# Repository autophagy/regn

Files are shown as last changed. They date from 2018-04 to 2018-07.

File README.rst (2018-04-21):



Regn is a weather station. It reads in temperature humidity,
atmospheric pressure and luminosity.

Hardware
========

- `ESP8266 Huzzah`_
- `DHT22 temperature & humidity sensor`_
- `BMP180 barometric pressure sensor`_
- `TSL2561 luminosity/lux/light sensor`_

Schematic
---------

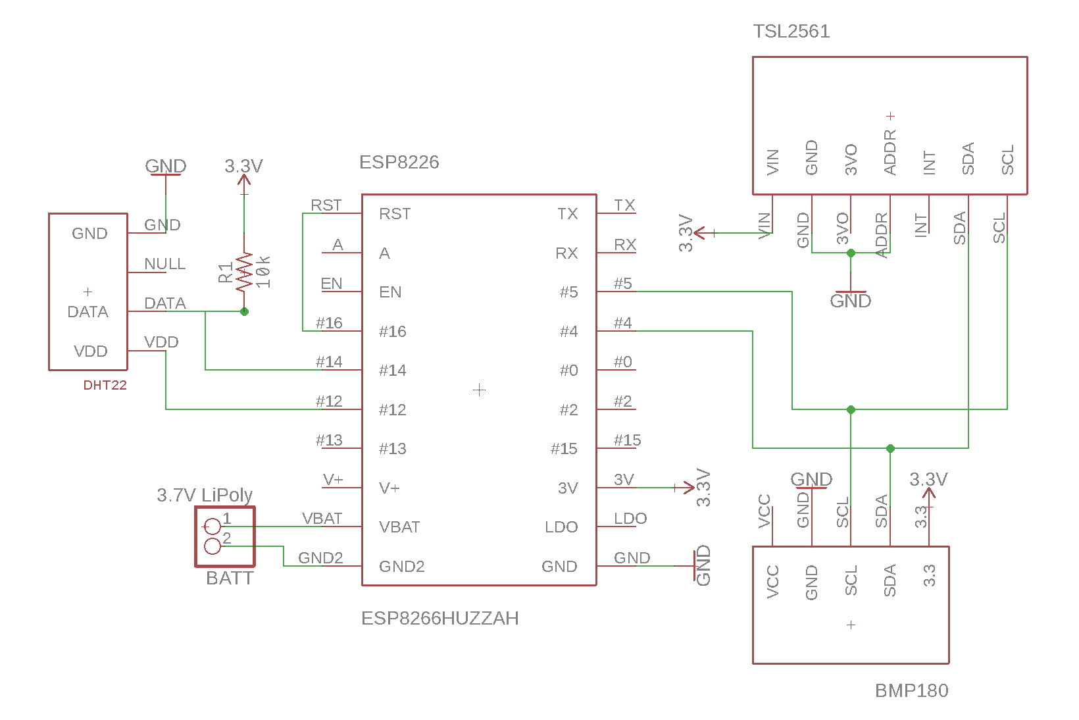
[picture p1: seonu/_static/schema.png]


PCB
---

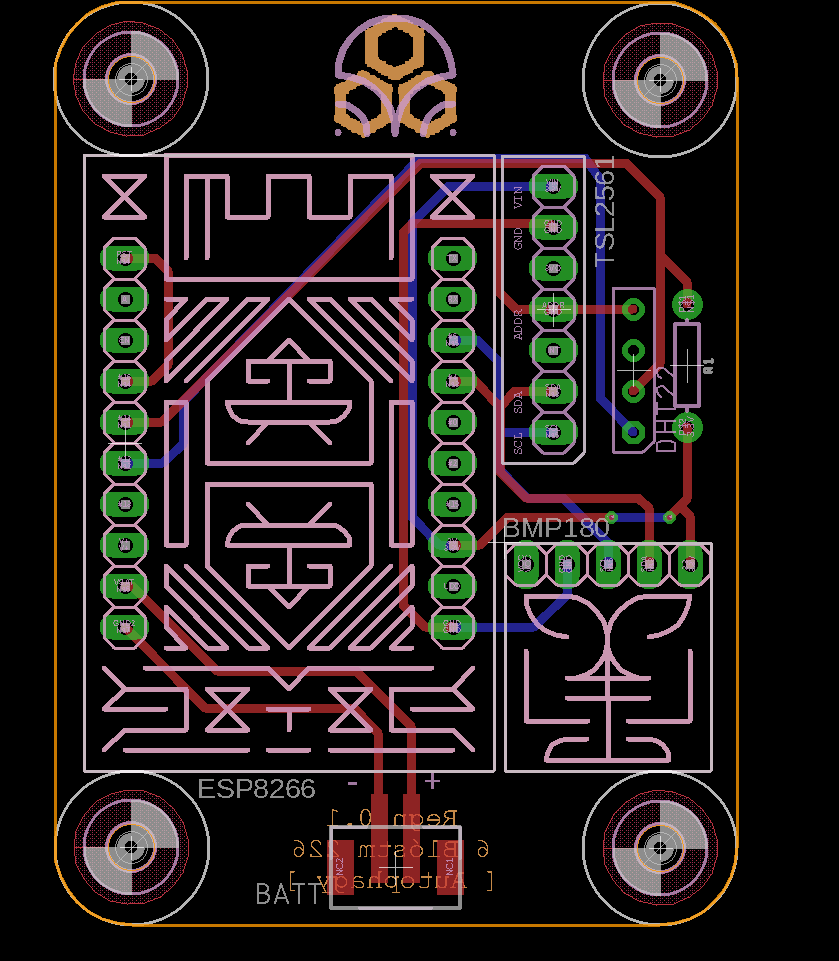
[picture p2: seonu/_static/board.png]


Front
~~~~~

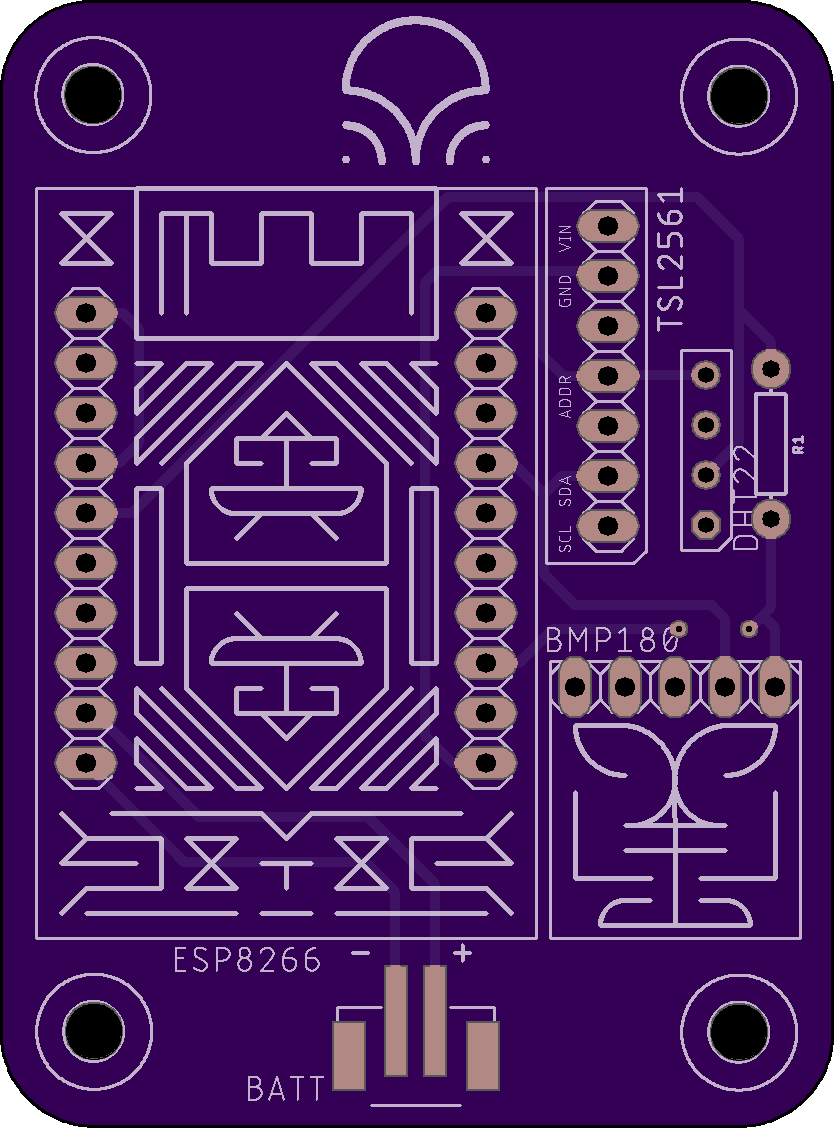
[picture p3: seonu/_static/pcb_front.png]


Back
~~~~

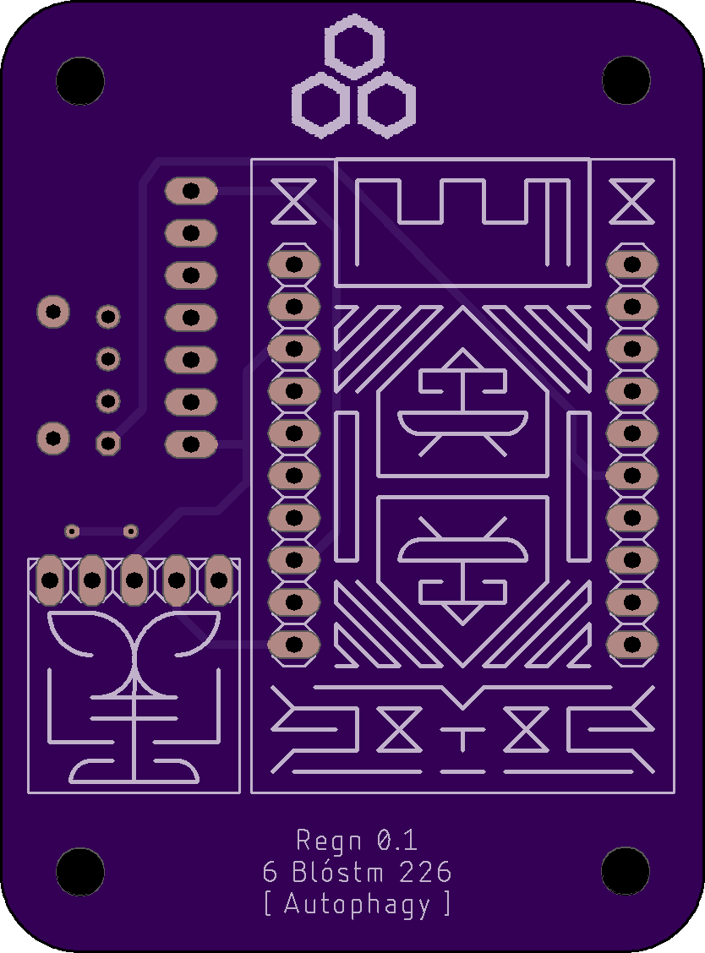
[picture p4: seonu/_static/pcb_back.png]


Software
========

Interface
---------

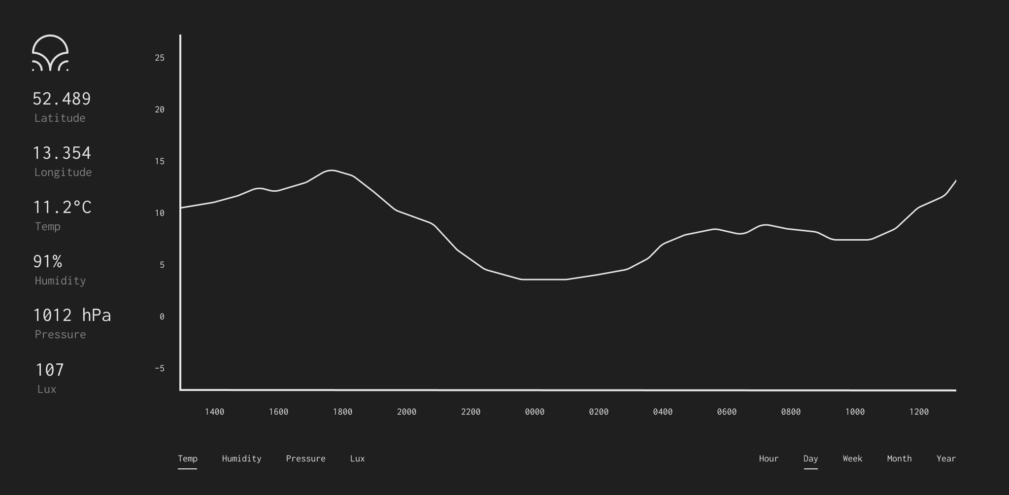
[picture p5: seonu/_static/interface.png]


.. _ESP8266 Huzzah: https://cdn-learn.adafruit.com/downloads/pdf/adafruit-huzzah-esp8266-breakout.pdf
.. _DHT22 temperature & humidity sensor: https://www.sparkfun.com/datasheets/Sensors/Temperature/DHT22.pdf
.. _BMP180 barometric pressure sensor: https://cdn-shop.adafruit.com/datasheets/BST-BMP180-DS000-09.pdf
.. _TSL2561 luminosity/lux/light sensor: https://cdn-shop.adafruit.com/datasheets/TSL2561.pdf

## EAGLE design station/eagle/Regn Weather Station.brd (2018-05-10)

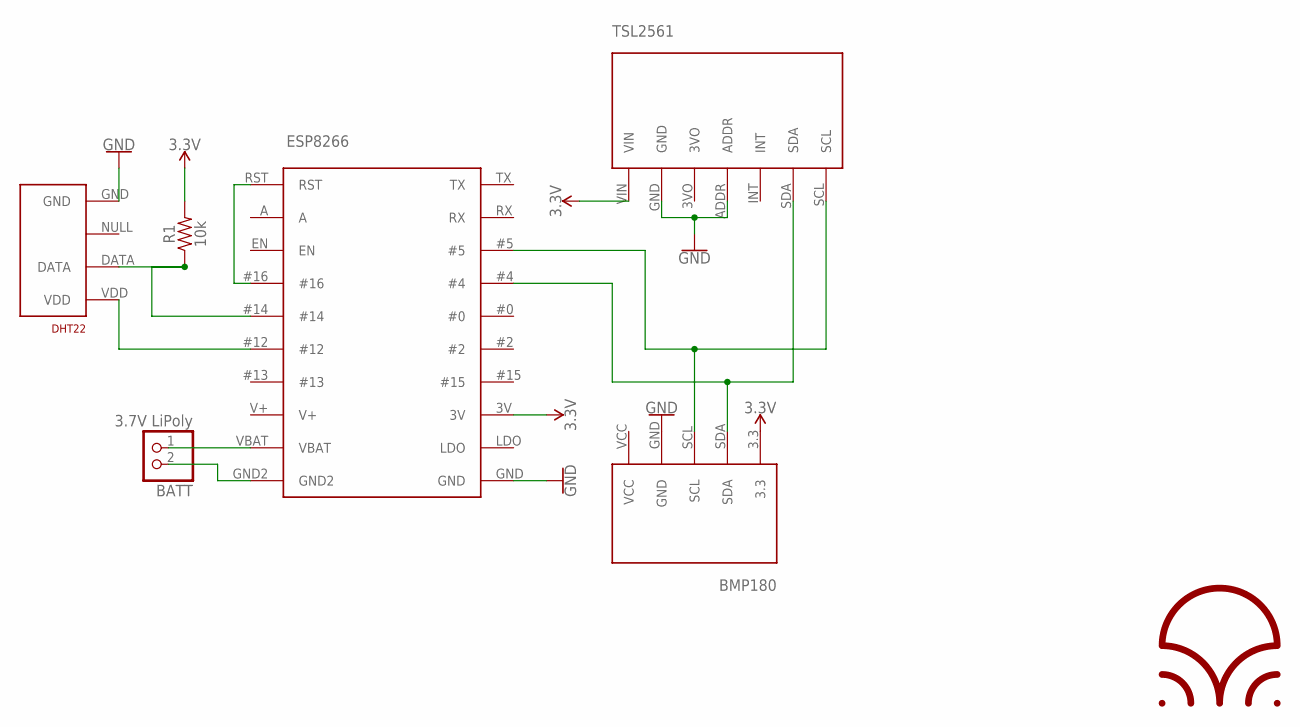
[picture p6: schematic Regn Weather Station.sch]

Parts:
BATT: 3.7V LiPoly; JST-PH-2-SMT
BMP180: BMP180
DHT22: RHT03_DHT-22_AM2302WIRED; AM2302
ESP8266: ESP8266HUZZAH
R1: 10k; AXIAL-0.3
TSL2561: TSL2561

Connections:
3.3V: BMP180.3.3, ESP8266.3V, R1.P$2 (2), TSL2561.VIN
GND: BMP180.GND, DHT22.GND, ESP8266.GND, TSL2561.ADDR, TSL2561.GND
unnamed: DHT22.DATA, ESP8266.#14, R1.P$1 (1)
unnamed: DHT22.VDD, ESP8266.#12
unnamed: BMP180.SDA, ESP8266.#4, TSL2561.SDA
unnamed: ESP8266.#16, ESP8266.RST
unnamed: BMP180.SCL, ESP8266.#5, TSL2561.SCL
unnamed: BATT.1 (2), ESP8266.VBAT
unnamed: BATT.2 (1), ESP8266.GND2
V+: ESP8266.V+
VCC: BMP180.VCC

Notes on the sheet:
/home/mika/images/regn.bmp

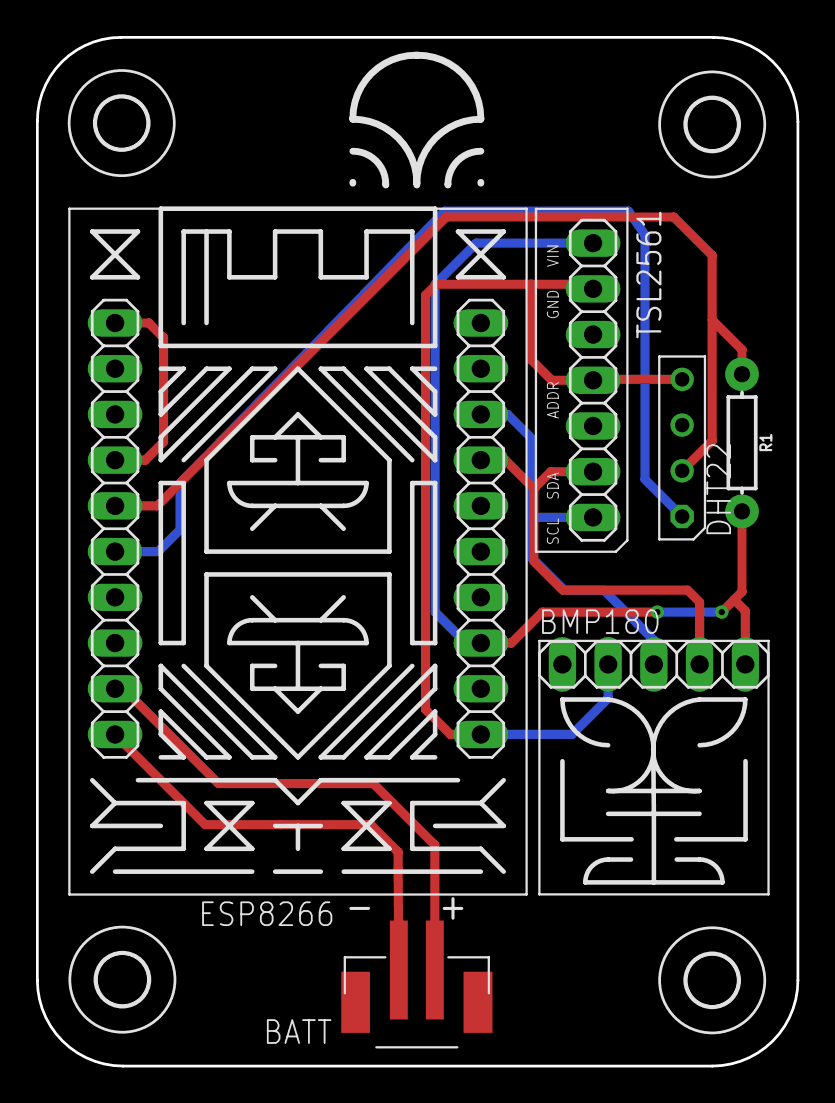
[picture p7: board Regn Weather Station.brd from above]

Board: 2 copper layers, 42.3 x 57.1 mm, 10 parts (0 on the bottom side), 9 nets.

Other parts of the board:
U$1, U$2, U$3, U$4: 2,8

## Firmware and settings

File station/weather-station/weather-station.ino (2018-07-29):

/*
  Regn :: Weather Station

  @version    0.1.0
  @author     Mika Naylor [Autophagy] :: http://autophagy.io/
  @hardware   Mika Naylor [Autophagy] :: http://autophagy.io/

  @description
  A client that reads temp, humidity, atmospheric pressure and
  luminosity at 10 minute intervals. POSTs these readings at a
  predefined endpoint, running the Regn server.

  Implementation Details :: https://github.com/Autophagy/regn
*/

// Libraries
#include <DHT.h>
#include <Adafruit_Sensor.h>
#include <Adafruit_TSL2561_U.h>
#include <Adafruit_BMP085_U.h>
#include <ESP8266HTTPClient.h>
#include <ESP8266WiFi.h>
#include <ArduinoJson.h>

// Constants
#define DHTPIN 14 // DHT22 connected to pin 14
#define DHTTYPE DHT22
DHT dht(DHTPIN, DHTTYPE);
Adafruit_TSL2561_Unified tsl = Adafruit_TSL2561_Unified(TSL2561_ADDR_LOW, 12345);
Adafruit_BMP085_Unified bmp = Adafruit_BMP085_Unified(10085);

// Connectivity
const char* ssid = "ssid";
const char* password = "password";

const char* host = "https://regn-weather.herokuapp.com/api/insert";
const char* fingerprint = "08 3B 71 72 02 43 6E CA ED 42 86 93 BA 7E DF 81 C4 BC 62 30";
const char* api_key = "apikey";


// Variables
bool DEBUG = true; // Set to true to output sensor information to the Serial port.

long sensor_interval = 600000; // 10 minutes
float temperature;
float humidity;
float pressure;
float lux;

void setup() {

  pinMode(12, OUTPUT);
  digitalWrite(12, HIGH);

  if (DEBUG) {
    Serial.begin(115200);
  }

  dht.begin();
  tsl.enableAutoRange(true);
  tsl.setIntegrationTime(TSL2561_INTEGRATIONTIME_13MS);
  bmp.begin();

  if (DEBUG) {
    Serial.print("Connecting to ");
    Serial.println(ssid);
  }

  WiFi.begin(ssid, password);

  if (DEBUG) {
    while (WiFi.status() != WL_CONNECTED) {
      delay(500);
      Serial.print(".");
    }

    Serial.println("");
    Serial.println("WiFi connected");
    Serial.println("IP address: ");
    Serial.println(WiFi.localIP());
    Serial.print("Netmask: ");
    Serial.println(WiFi.subnetMask());
    Serial.print("Gateway: ");
    Serial.println(WiFi.gatewayIP());
  }
}

void loop() {
  temperature = getTemperature();
  humidity = getHumidity();
  pressure = getPressure();
  lux = getLux();

  if (DEBUG) {
    outputDebugInfo();
  }

  // POST sensor readings to endpoint
  StaticJsonBuffer<300> JSONbuffer;
  JsonObject& JSONencoder = JSONbuffer.createObject();
  JSONencoder["temperature"] = temperature;
  JSONencoder["humidity"] = humidity;
  JSONencoder["pressure"] = pressure;
  JSONencoder["luminosity"] = lux;
  char JSONmessageBuffer[300];
  JSONencoder.prettyPrintTo(JSONmessageBuffer, sizeof(JSONmessageBuffer));

  if (DEBUG) {
    Serial.println("JSON Data:");
    Serial.println(JSONmessageBuffer);
  }

  int code = -1;
  HTTPClient http;
  while(code != 201) {
    http.begin(host, fingerprint);
    http.addHeader("Content-Type", "application/json");
    http.addHeader("x-api-key", api_key);
    code = http.POST(JSONmessageBuffer);

    if (DEBUG) {
      Serial.println(code);
      Serial.println(http.getString());
    }

    http.end();
    delay(1000);
  }

  // Delay by sensor_interval for each read

  delay(sensor_interval);
}

// Returns the temperature reading from the DHT22 sensor
float getTemperature() {
  return dht.readTemperature();
}

// Returns the humidity reading from the DHT22 sensor
float getHumidity() {
  return dht.readHumidity();
}

// Returns the pressure reading from the BMP180 sensor
float getPressure() {
  sensors_event_t event;
  bmp.getEvent(&event);
  return event.pressure;
}

// Returns the lux reading from the TSL2561 sensor
float getLux() {
  sensors_event_t event;
  tsl.getEvent(&event);
  return event.light;
}

// Prints sensor info out to Serial for debugging purposes
void outputDebugInfo() {
  Serial.println("------------------------------------");

  Serial.print("Temperature: ");
  Serial.print(temperature);
  Serial.println(" *C");

  Serial.print("Humidity: ");
  Serial.print(humidity);
  Serial.println(" %\t");

  Serial.print("Barometric pressure: ");
  Serial.print(pressure);
  Serial.println(" hPa");

  Serial.print("Luminosity: ");
  Serial.print(lux);
  Serial.println(" lux");

  Serial.println("------------------------------------");
}

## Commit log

2018-04-01 Initial commit of schematics
    [weather-station.fzz]
2018-04-01 Remove bluetooth module
    [weather-station.fzz]
2018-04-07 Convert station code from arduino to ESP8266
2018-04-07 Update station schematics
    [weather-station.fzz]
2018-04-07 Remove arduino refernces
2018-04-08 Add 10k pullup to DHT22 data pin
2018-04-08 Add sensor data insert json schema + validation
2018-04-08 Experimentation with db, add insert and latest
2018-04-08 Add sensor/range/since api
2018-04-09 Fix luminosity label on station
    [weather-station.ino]
2018-04-09 Add timestamp to sensor get
2018-04-10 Add prototype dashboard that calls from API
2018-04-10 Add mode and granularity switching to dashboard obj
2018-04-11 Tweak x axis ticks
2018-04-14 Add sensor type controls
2018-04-15 Add API key check for insert endpoint
2018-04-15 Refactor sample data generator to use development api key
2018-04-16 Reorder sensor controls
2018-04-16 Add check for zero values from sensors
2018-04-20 Updated station schematics to include 3.7v lipo, pin 16 -> RST for deepsleep, toggleable 3.3v rail for dht22
    [weather-station.fzz]
2018-04-21 Move diagrams from Fritzing to Eagle
    Also create prelim prototype PCB
    [Regn Weather Station.brd, Regn Weather Station.sch, weather-station.fzz]
2018-04-22 Refactored PCB size and logos
    [Regn Weather Station.brd, Regn Weather Station.sch]
2018-04-22 Increased trace width 0.6 -> 1.0 mil
    [Regn Weather Station.brd, Regn Weather Station.sch]
2018-04-23 Increased trace width from 10 mil to 20 mil
    [Regn Weather Station.brd]
2018-04-23 Fix some clearance issues
    [Regn Weather Station.brd]
2018-05-10 PCB optimizations and refining
    [Regn Weather Station.brd, Regn Weather Station.sch]
2018-07-29 DHT22 on pin 14, powered by pin 12

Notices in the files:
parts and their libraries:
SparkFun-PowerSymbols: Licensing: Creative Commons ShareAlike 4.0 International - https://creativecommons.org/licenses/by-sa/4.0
